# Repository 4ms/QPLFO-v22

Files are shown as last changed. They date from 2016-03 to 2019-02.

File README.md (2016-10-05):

#QPLFO v2.2
(also known as QPLFO v3)

This code runs on the STM32F030 version of the QPLFO, which is the factory-assembled version after March 2016. This code will not work on any kit versions of the QPLFO, nor any PCBs labeled version 1.x (green PCBs).

Note that one of the SWD programming pins is also used for the UI, so once the code has been flashed, it is difficult to re-flash it. The best technique I've found is to hit the reset button on the PCB at the right moment just before flashing.

This project was began using the [STM32F030x4 Application Template] (https://github.com/MrSpock/stm32f030x-gcc-template) from Martin Jurczuk, which is highly based on Mike Szczys [STM32F0-DISCOVERY template] (https://github.com/szczys/stm32f0-discovery-basic-template)

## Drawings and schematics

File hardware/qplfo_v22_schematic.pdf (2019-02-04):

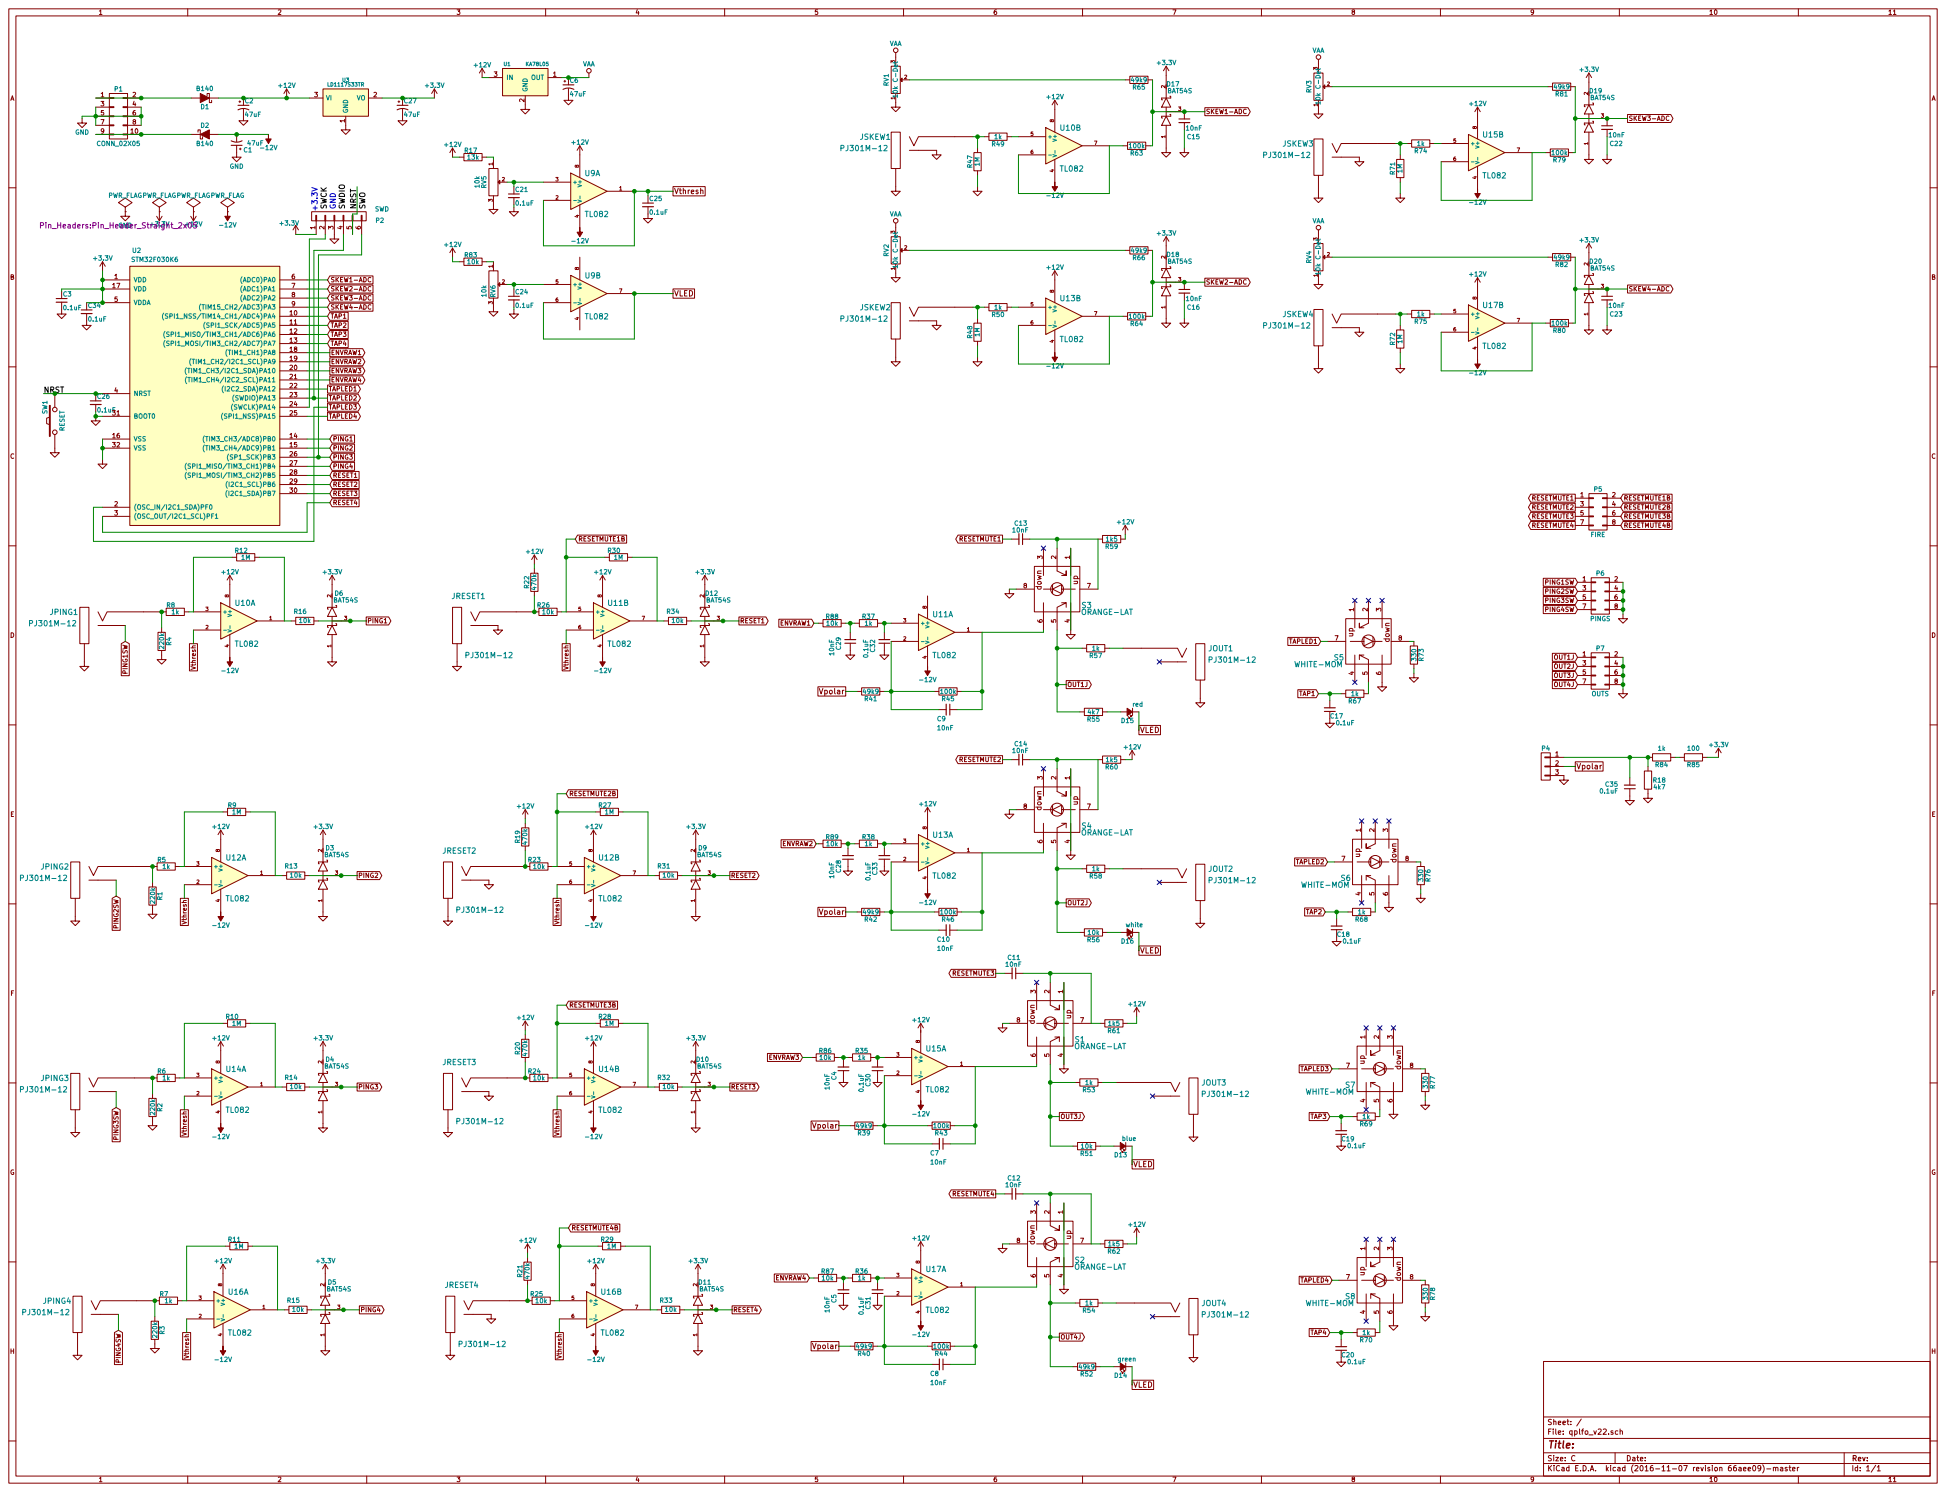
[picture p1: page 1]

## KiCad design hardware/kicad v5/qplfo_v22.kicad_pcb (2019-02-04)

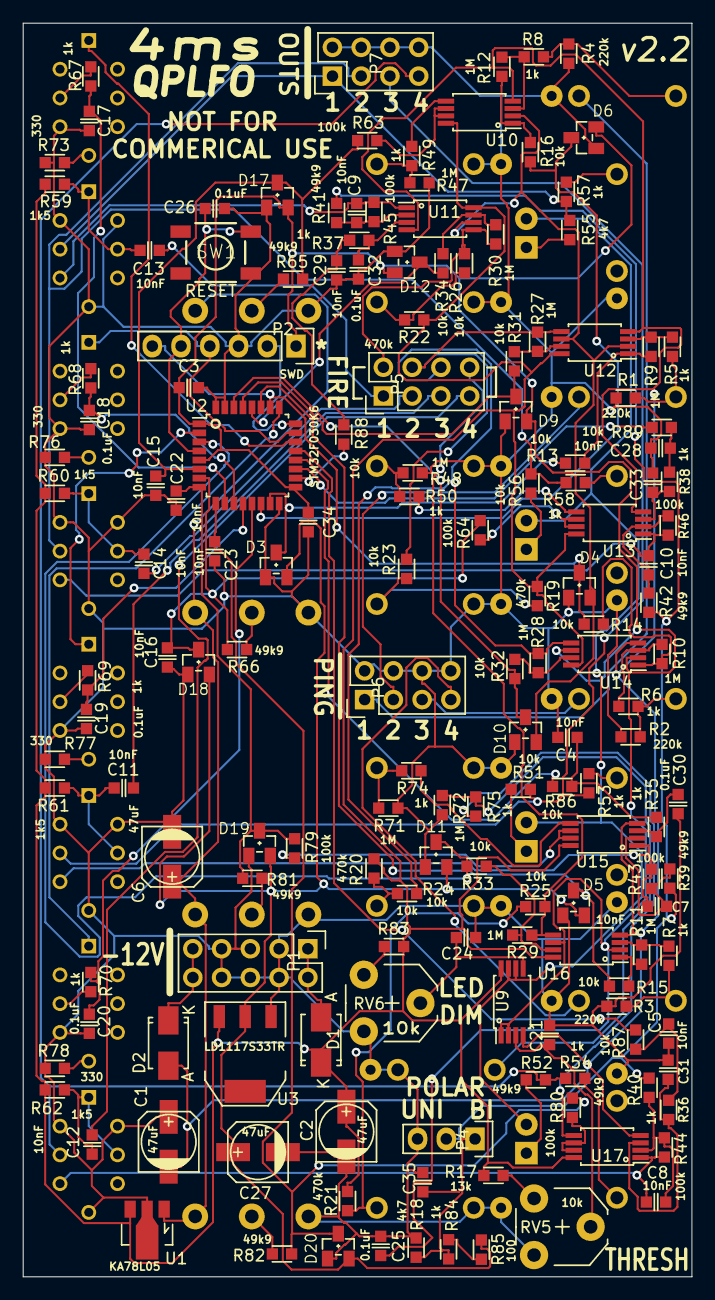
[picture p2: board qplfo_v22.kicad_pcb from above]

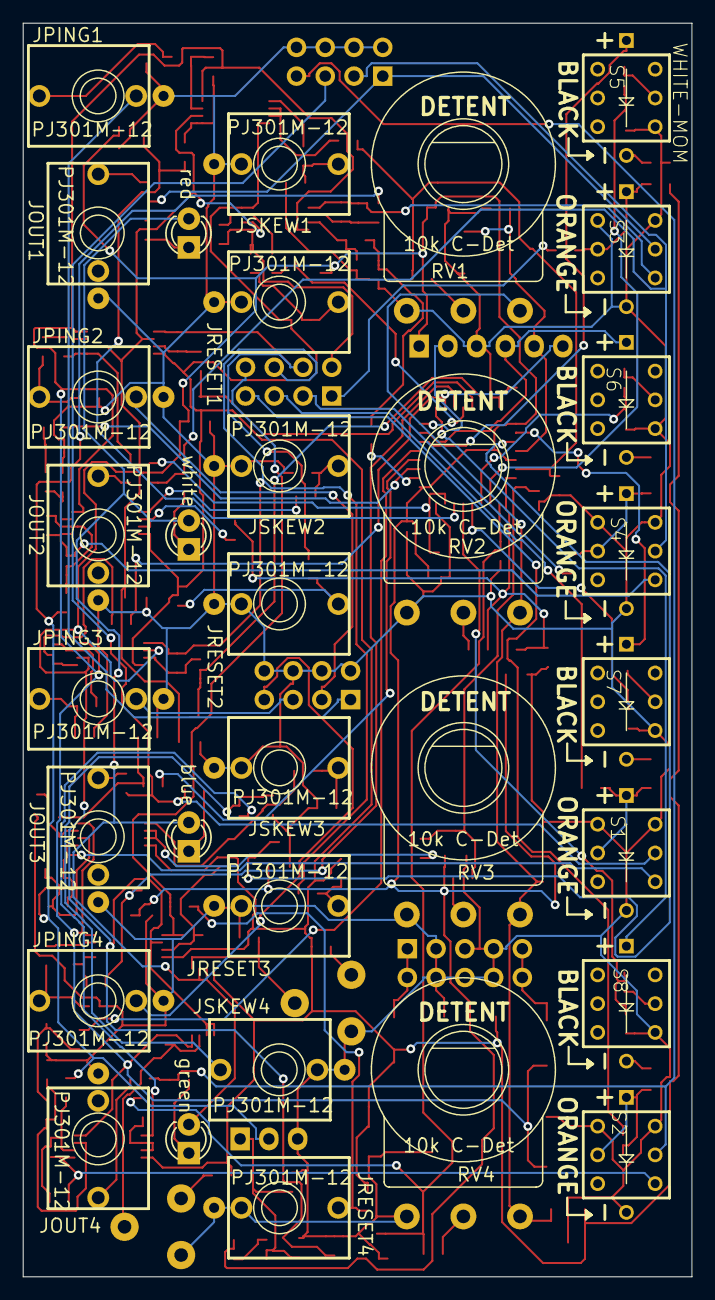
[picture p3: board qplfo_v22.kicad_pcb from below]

Board: 2 copper layers, 59.1 x 110.7 mm, 191 parts (32 on the bottom side), 130 nets.

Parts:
C1, C2, C6, C27: 47uF; c_elec_5x5.3
C3, C17, C18, C19, C20, C21, C24, C25, C26, C30, C31, C32, C33, C34, C35: 0.1uF; C0603
C4, C5, C7, C8, C9, C10, C11, C12, C13, C14, C15, C16, C22, C23, C28, C29: 10nF; C0603
D1, D2: B140; Diode-SMA_Standard
D3, D4, D5, D6, D9, D10, D11, D12, D17, D18, D19, D20: BAT54S; SOT23
D13: blue; LED-3MM-SQUARE-ANODE
D14: green; LED-3MM-SQUARE-ANODE
D15: red; LED-3MM-SQUARE-ANODE
D16: white; LED-3MM-SQUARE-ANODE
JOUT1, JOUT2, JOUT3, JOUT4: PJ301M-12; PJ301M-12-FIX
JPING1, JPING2, JPING3, JPING4: PJ301M-12; PJ301M-12-FIX
JRESET1, JRESET2, JRESET3, JRESET4: PJ301M-12; PJ301M-12-FIX
JSKEW1, JSKEW2, JSKEW3, JSKEW4: PJ301M-12; PJ301M-12-FIX
P1: CONN_02X05; Pin_Header_Straight_2x05
P2: SWD; Pin_Header_Straight_1x06
P4: HEADER-MALE-1X3-TH; Pin_Header_Straight_1x03
P5: FIRE; Pin_Header_Straight_2x04
P6: PINGS; Pin_Header_Straight_2x04
P7: OUTS; Pin_Header_Straight_2x04
R1, R2, R3, R4: 220k; R0603
R5, R6, R7, R8, R35, R36, R37, R38, R49, R50, R53, R54, R57, R58, R67, R68, R69, R70, R74, R75, R84: 1k; R0603
R9, R10, R11, R12, R27, R28, R29, R30, R47, R48, R71, R72: 1M; R0603
R13, R14, R15, R16, R23, R24, R25, R26, R31, R32, R33, R34, R51, R56, R83, R86, R87, R88, R89: 10k; R0603
R17: 13k; R0603
R18, R55: 4k7; R0603
R19, R20, R21, R22: 470k; R0603
R39, R40, R41, R42, R52, R65, R66, R81, R82: 49k9; R0603
R43, R44, R45, R46, R63, R64, R79, R80: 100k; R0603
R59, R60, R61, R62: 1k5; R0603
R73, R76, R77, R78: 330; R0603
R85: 100; R0603
RV1, RV2, RV3, RV4: 10k C-Det; 16MM-RV16AF-4A
RV5, RV6: 10k; Potentiometer_VishaySpectrol-Econtrim-Type36M
S1, S2, S3, S4: ORANGE-LAT; BUTTON-LED-PB61303
S5, S6, S7, S8: WHITE-MOM; BUTTON-LED-PB61303
SW1: RESET; BUTTON-TACT-SKQG
U1: KA78L05; SOT89-3_Housing
U2: STM32F030K6; LQFP-32_7x7mm_Pitch0.8mm
U3: LD1117S33TR; SOT-223
U9, U10, U11, U12, U13, U14, U15, U16, U17: TL082; TSSOP-8_4.4x3mm_Pitch0.65mm

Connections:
+3V3: C3.1, C27.1, C34.1, D3.2, D4.2, D5.2, D6.2, D9.2, D10.2, D11.2, D12.2, D17.2, D18.2, D19.2, D20.2, P2.1, R85.2, U2.1, U2.5, U2.17, U3.2
+12V: C2.1, D1.1, R17.2, R19.2, R20.2, R21.2, R22.2, R59.1, R60.1, R61.1, R62.1, R83.2, U1.3, U3.3, U9.8, U10.8, U11.8, U12.8, U13.8, U14.8, U15.8, U16.8, U17.8
-12V: C1.2, D2.2, U9.4, U10.4, U11.4, U12.4, U13.4, U14.4, U15.4, U16.4, U17.4
/NRST: C26.1, P2.5, SW1.2, U2.4
ENVRAW1: R88.2, U2.18
ENVRAW2: R89.2, U2.19
ENVRAW3: R86.2, U2.20
ENVRAW4: R87.2, U2.21
GND: C1.1, C2.2, C3.2, C4.1, C5.1, C6.2, C15.2, C16.2, C17.1, C18.1, C19.1, C20.1, C21.2, C22.2, C23.2, C24.2, C25.2, C26.2, C27.2, C28.1, C29.1, C30.1, C31.1, C32.1, C33.1, C34.2, C35.1, D3.1, D4.1, D5.1, D6.1, D9.1, D10.1, D11.1, D12.1, D17.1, D18.1, D19.1, D20.1, JOUT1.2, JOUT2.2, JOUT3.2, JOUT4.2, JPING1.2, JPING2.2, JPING3.2, JPING4.2, JRESET1.2, JRESET1.3, JRESET2.2, JRESET2.3, JRESET3.2, JRESET3.3, JRESET4.2, JRESET4.3, JSKEW1.2, JSKEW1.3, JSKEW2.2, JSKEW2.3, JSKEW3.2, JSKEW3.3, JSKEW4.2, JSKEW4.3, P1.3, P1.4, P1.5, P1.6, P1.7, P1.8, P2.3, P4.3, P6.2, P6.4, P6.6, P6.8, P7.2, P7.4, P7.6, P7.8, R1.2, R2.2, R3.2, R4.2, R18.2, R47.1, R48.1, R71.1, R72.1, R73.1, R76.1, R77.1, R78.1, RV1.1, RV2.1, RV3.1, RV4.1, RV5.3, RV6.3, S1.1, S1.4, S1.8, S2.1, S2.4, S2.8, S3.1, S3.4, S3.8, S4.1, S4.4, S4.8, S5.6, S6.6, S7.6, S8.6, SW1.1, U1.2, U2.16, U2.31, U2.32, U3.1
unnamed: C4.2, R35.2, R86.1
unnamed: C5.2, R36.2, R87.1
unnamed: C7.1, R43.1, S1.6, U15.1
unnamed: C7.2, R39.1, R43.2, U15.2
unnamed: C8.1, R44.1, S2.6, U17.1
unnamed: C8.2, R40.1, R44.2, U17.2
unnamed: C9.1, R45.1, S3.6, U11.1
unnamed: C9.2, R41.1, R45.2, U11.2
unnamed: C10.1, R46.1, S4.6, U13.1
unnamed: C10.2, R42.1, R46.2, U13.2
unnamed: C11.1, R61.2, S1.2, S1.7
unnamed: C12.1, R62.2, S2.2, S2.7
unnamed: C13.1, R59.2, S3.2, S3.7
unnamed: C14.1, R60.2, S4.2, S4.7
unnamed: C21.1, RV5.2, U9.3
unnamed: C24.1, RV6.2, U9.5
unnamed: C28.2, R38.2, R89.1
unnamed: C29.2, R37.2, R88.1
unnamed: C30.2, R35.1, U15.3
unnamed: C31.2, R36.1, U17.3
unnamed: C32.2, R37.1, U11.3
unnamed: C33.2, R38.1, U13.3
unnamed: C35.2, P4.1, R18.1, R84.1
unnamed: D1.2, P1.1, P1.2
unnamed: D2.1, P1.9, P1.10
unnamed: D13.2, R51.1
unnamed: D14.2, R52.1
unnamed: D15.2, R55.1
unnamed: D16.2, R56.1
unnamed: JOUT1.1, R57.1
unnamed: JOUT2.1, R58.1
unnamed: JOUT3.1, R53.1
unnamed: JOUT4.1, R54.1
unnamed: JPING1.1, R4.1, R8.2
unnamed: JPING2.1, R1.1, R5.2
unnamed: JPING3.1, R2.1, R6.2
unnamed: JPING4.1, R3.1, R7.2
unnamed: JRESET1.1, R22.1, R26.2
unnamed: JRESET2.1, R19.1, R23.2
unnamed: JRESET3.1, R20.1, R24.2
unnamed: JRESET4.1, R21.1, R25.2
unnamed: JSKEW1.1, R47.2, R49.2
unnamed: JSKEW2.1, R48.2, R50.2
unnamed: JSKEW3.1, R71.2, R74.2
unnamed: JSKEW4.1, R72.2, R75.2
unnamed: P2.2, U2.24
unnamed: R5.1, R9.2, U12.3
unnamed: R10.1, R14.1, U14.1
unnamed: R6.1, R10.2, U14.3
unnamed: R11.1, R15.1, U16.1
unnamed: R7.1, R11.2, U16.3
unnamed: R12.1, R16.1, U10.1
unnamed: R8.1, R12.2, U10.3
unnamed: R9.1, R13.1, U12.1
unnamed: R17.1, RV5.1
unnamed: R27.1, R31.1, U12.7
unnamed: R28.1, R32.1, U14.7
unnamed: R29.1, R33.1, U16.7
unnamed: R30.1, R34.1, U11.7
unnamed: R49.1, U10.5
unnamed: R50.1, U13.5
unnamed: R63.2, U10.6, U10.7
unnamed: R64.2, U13.6, U13.7
unnamed: R65.2, RV1.2
unnamed: R66.2, RV2.2
unnamed: R67.2, S5.5
unnamed: R68.2, S6.5
unnamed: R69.2, S7.5
unnamed: R70.2, S8.5
unnamed: R73.2, S5.8
unnamed: R74.1, U15.5
unnamed: R75.1, U17.5
unnamed: R76.2, S6.8
unnamed: R77.2, S7.8
unnamed: R78.2, S8.8
unnamed: R79.2, U15.6, U15.7
unnamed: R80.2, U17.6, U17.7
unnamed: R81.2, RV3.2
unnamed: R82.2, RV4.2
unnamed: R83.1, RV6.1
unnamed: R84.2, R85.1
OUT1J: P7.1, R55.2, R57.2, S3.5
OUT2J: P7.3, R56.2, R58.2, S4.5
OUT3J: P7.5, R51.2, R53.2, S1.5
OUT4J: P7.7, R52.2, R54.2, S2.5
PING1: D6.3, R16.2, U2.14
PING1SW: JPING1.3, P6.1
PING2: D3.3, R13.2, U2.15
PING2SW: JPING2.3, P6.3
PING3: D4.3, P2.6, R14.2, U2.26
PING3SW: JPING3.3, P6.5
PING4: D5.3, R15.2, U2.27
PING4SW: JPING4.3, P6.7
RESET1: D12.3, R34.2, U2.28
RESET2: D9.3, R31.2, U2.29
RESET3: D10.3, R32.2, U2.30
RESET4: D11.3, R33.2, U2.3
RESETMUTE1: C13.2, P5.1
RESETMUTE1B: P5.2, R26.1, R30.2, U11.5
RESETMUTE2: C14.2, P5.3
RESETMUTE2B: P5.4, R23.1, R27.2, U12.5
RESETMUTE3: C11.2, P5.5
RESETMUTE3B: P5.6, R24.1, R28.2, U14.5
RESETMUTE4: C12.2, P5.7
RESETMUTE4B: P5.8, R25.1, R29.2, U16.5
SKEW1-ADC: C15.1, D17.3, R63.1, R65.1, U2.6
SKEW2-ADC: C16.1, D18.3, R64.1, R66.1, U2.7
SKEW3-ADC: C22.1, D19.3, R79.1, R81.1, U2.8
SKEW4-ADC: C23.1, D20.3, R80.1, R82.1, U2.9
TAP1: C17.2, R67.1, U2.10
TAP2: C18.2, R68.1, U2.11
TAP3: C19.2, R69.1, U2.12
TAP4: C20.2, R70.1, U2.13
TAPLED1: S5.7, U2.22
TAPLED2: P2.4, S6.7, U2.23
TAPLED3: S7.7, U2.2
TAPLED4: S8.7, U2.25
VAA: C6.1, RV1.3, RV2.3, RV3.3, RV4.3, U1.1
VLED: D13.1, D14.1, D15.1, D16.1, U9.6, U9.7
Vpolar: P4.2, R39.2, R40.2, R41.2, R42.2
Vthresh: C25.1, U9.1, U9.2, U10.2, U11.6, U12.2, U12.6, U14.2, U14.6, U16.2, U16.6

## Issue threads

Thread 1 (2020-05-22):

qplfo_v22-rescue.lib missing

okelk, 2020-05-22:
Schematic file is unusable because it references "qplfo_v22-rescue.lib" that is not included in the folder.
I'm using kicad 5.1.5.

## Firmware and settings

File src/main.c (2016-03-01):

#include "stm32f0xx_conf.h"
#include "dig_inouts.h"
#include "pwm.h"
#include "adc.h"


//#define FREERUN


/************************
 * Time keeping			*
 ************************/
volatile uint32_t tmr_ping[4]={0,0,0,0};
volatile uint32_t tmr_reset[4]={0,0,0,0};
volatile uint32_t tmr_tapin[4]={0,0,0,0};
volatile uint32_t tmr_tapout[4]={0,0,0,0};
volatile uint32_t ping_irq_timestamp[4]={0,0,0,0};

/************************
 * Mnuemonics			*
 ************************/
#define WAIT 0
#define RISE 1
#define FALL 2


/********************
 * Settings			*
 ********************/
#define ADC_DRIFT 50

#define PLUCKY_CURVE_ADC 130
#define PLUCKY_CUBIC_ADC 90
#define PLUCKY_QUADRATIC_ADC 55
#define TRIGOUT_CURVE_ADC 30

#define TRIGOUT_WIDTH 50

#define SKEW_TRACKING_TIME 4000

#define HOLDTIMECLEAR 15000

/********************
 * Global variables	*
 ********************/
volatile uint8_t timer_overflowed=0;
uint8_t ping_state[4]={0,0,0,0};
volatile uint8_t clk_time_changed[4]={0,0,0,0};
volatile uint16_t adc_buffer[4];
int16_t t_dacout[4]={0,0,0,0};


void SysTick_Handler(void) {

 	tmr_ping[0]++;
	tmr_ping[1]++;
	tmr_ping[2]++;
	tmr_ping[3]++;
	tmr_reset[0]++;
	tmr_reset[1]++;
	tmr_reset[2]++;
	tmr_reset[3]++;
	tmr_tapin[0]++;
	tmr_tapin[1]++;
	tmr_tapin[2]++;
	tmr_tapin[3]++;
	tmr_tapout[0]++;
	tmr_tapout[1]++;
	tmr_tapout[2]++;
	tmr_tapout[3]++;

	timer_overflowed++;
}


void init_tmrs(void)
{
	tmr_ping[0]=0;
	tmr_ping[1]=0;
	tmr_ping[2]=0;
	tmr_ping[3]=0;
	tmr_reset[0]=0;
	tmr_reset[1]=0;
	tmr_reset[2]=0;
	tmr_reset[3]=0;
	tmr_tapin[0]=0;
	tmr_tapin[1]=0;
	tmr_tapin[2]=0;
	tmr_tapin[3]=0;
	tmr_tapout[0]=0;
	tmr_tapout[1]=0;
	tmr_tapout[2]=0;
	tmr_tapout[3]=0;
}

inline uint8_t diff(uint8_t a, uint8_t b);
inline uint8_t diff(uint8_t a, uint8_t b){
	if (a>b) return (a-b);
	else return (b-a);
}
/*
#define delay()					\
do {							\
  register unsigned int i;		\
  for (i = 0; i < 1000000; ++i)	\
    __asm__ __volatile__ ("nop\n\t":::"memory");\
} while (0)
*/

uint32_t calc_rise_time(uint32_t skew_val, uint32_t period);
uint32_t calc_rise_time(uint32_t skew_val, uint32_t period)
{
	if (skew_val<=(PLUCKY_CURVE_ADC+ADC_DRIFT+ADC_DRIFT))
	{
		return(1);
	}
	else if (skew_val>4000)
	{
		return(period-1);
	}
	else if ((skew_val>1975) && (skew_val<2125))
	{
		return(period>>1);
	}
	else
	{
		return((skew_val * period) >> 12);
	}
}

int main(void)
{
	uint32_t clk_time[4]={0,0,0,0};

	uint8_t env_state[4]={RISE, RISE, RISE, RISE};
	uint8_t reset_now_flag[4]={0,0,0,0};

	uint32_t rise_time[4]={0,0,0,0};
	uint32_t fall_time[4]={0,0,0,0};

	uint32_t rise_inc[4]={0,0,0,0};
	uint32_t fall_inc[4]={0,0,0,0};
	uint32_t accum[4]={0,0,0,0};

	uint32_t reset_offset_time[4]={0,0,0,0};
	uint8_t ready_to_reset[4]={0,0,0,0};
	uint8_t reset_up[4]={0,0,0,0};

	uint32_t skew_adc[4]={2047,2047,2047,2047};

	uint8_t do_plucky_curve[4]={0,0,0,0};
	uint32_t sample_ctr[4]={0,0,0,0};
	uint32_t is_modulating_skew[4]={0,0,0,0};

	uint8_t t=0;
	uint8_t i;
	uint32_t t32=0;
	uint16_t t16;
	uint32_t new_clk_time;

	uint8_t t_of;

	uint32_t now;

	uint8_t chan=0;

	uint8_t running[4];
	uint8_t tapin_up[4]={0,0,0,0};
	uint8_t tapled_state[4];
	uint8_t ping_high[4]={0,0,0,0};


	/** Initialize **/

	init_tmrs();
	init_dig_inouts();
	init_adc((uint16_t *)adc_buffer);

	//delay();

	init_pwm();
	SysTick_Config(SystemCoreClock/10000); //1000 is 1ms ticks, 10000 is 100us ticks, 100000 is 10us ticks

	TAPLED_OFF(1);
	TAPLED_OFF(2);
	TAPLED_OFF(3);
	TAPLED_OFF(0);
	tapled_state[0]=0;
	tapled_state[1]=0;
	tapled_state[2]=0;
	tapled_state[3]=0;

	running[0]=0;
	running[1]=0;
	running[2]=0;
	running[3]=0;

	clk_time[0]=0;
	clk_time[1]=0;
	clk_time[2]=0;
	clk_time[3]=0;

	while (1){

		if (++chan>=4) chan=0;

		/***************** READ PING *********************
		 *  On rising edge of input ping, record the time
		 *  since the last ping. Save this into clk_time
		 *************************************************/

		if (TAPBUT(chan))
		{
			if (!(tapin_up[chan]))
			{
				if (running[chan]==1) running[chan]=2;
				else if (running[chan]==0) running[chan]=1;

				tapled_state[chan]=1;
				TAPLED_ON(chan);
				tapin_up[chan]=1;

				clk_time[chan] = tmr_tapin[chan];

				tmr_tapin[chan]=0;
				tmr_tapout[chan]=0;
				tmr_reset[chan]=0;
				ready_to_reset[chan]=1;

				clk_time_changed[chan]=1;
			}
			//Check for long hold of tap button
			if (tmr_tapin[chan] > HOLDTIMECLEAR)
			{
				if (running[chan])
				{
					TAPLED_OFF(chan);
					tapled_state[chan]=0;
				}
				running[chan]=0;
				//clk_time[chan]=0;
			}
		} else {
			if (tapin_up[chan])
			{
				tapin_up[chan]=0;
				tapled_state[chan]=0;
				TAPLED_OFF(chan);
			}
		}


		if (PING(chan))
		{
			if (!(ping_high[chan])){
				running[chan]=2;

				tapled_state[chan]=1;
				TAPLED_ON(chan);
				ping_high[chan]=1;

				new_clk_time = tmr_ping[chan];

				if (new_clk_time > clk_time[chan])	t32=new_clk_time - clk_time[chan];
				else t32=clk_time[chan]-new_clk_time;

				if (t32>10){ //better would be to make it a percent of clk_time
					clk_time[chan] = new_clk_time;
					clk_time_changed[chan]=1;
				}

				tmr_ping[chan]=0;
				tmr_tapout[chan]=0;
				tmr_reset[chan]=0;
				ready_to_reset[chan]=1;

			}
		} else {
			if (ping_high[chan]){
				ping_high[chan]=0;
				tapled_state[chan]=0;
				TAPLED_OFF(chan);
			}
		}


		//
		// Flash the TAP button LED with a 50% duty cycle
		// Reset Tap LED timer if it overflows the channel's period
		//
		if (running[chan]==2){
			now = tmr_tapout[chan];
			if (tapled_state[chan] && (now >= (clk_time[chan] >> 1)))
			{
				tapled_state[chan]=0;
				TAPLED_OFF(chan);
			}

			if (now >= clk_time[chan]){
				t32 = (now - clk_time[chan]);
				tmr_tapout[chan]=t32;
				tmr_reset[chan]=t32;

				//tmr_tapout[chan]=0;

				tapled_state[chan]=1;
				ready_to_reset[chan]=1;
				TAPLED_ON(chan);
			}
		}


		if (clk_time_changed[chan])
		{
			clk_time_changed[chan]=0;

			tmr_reset[chan]=0;

			//clk_time changed, so see if reset_offset_time is still valid
			//reset it to 0 if it's greater than the ping period or 2ms under the period
			if ((reset_offset_time[chan]+20)>=clk_time[chan]) {
				reset_offset_time[chan]=0;
			}

			ready_to_reset[chan]=1;

			rise_time[chan] = calc_rise_time(skew_adc[chan], clk_time[chan]);
			fall_time[chan] = clk_time[chan] - rise_time[chan];

			rise_inc[chan] = (1<<28)/(rise_time[chan]);
			fall_inc[chan] = (1<<28)/(fall_time[chan]);

		}



		if (RESETJACK(chan))
		{
			if (!reset_up[chan])
			{
			//	if (env_state!=WAIT){
					reset_offset_time[chan]=tmr_reset[chan];

					//see if the new reset_offset_time is still valid
					//reset it to 0 if it's greater than the ping period or 2ms under the period
					if ((reset_offset_time[chan]+20)>=clk_time[chan]) {
						reset_offset_time[chan]=0;
					}
			//	}

				reset_now_flag[chan]=1;
				reset_up[chan]=1;
				ready_to_reset[chan]=0;
			}
			else
			{
				if (env_state[chan]!=WAIT)
					ready_to_reset[chan]=0; //disable resetting if RESET is held high "analog mode"
			}
		}
		else
		{
			reset_up[chan]=0;
		}



		/*******************
		*
		* Reset Lock Point
		*
		********************/

		t32=tmr_reset[chan];

		if (ready_to_reset[chan] && (t32>reset_offset_time[chan]))
		{
			//If we haven't recently modulated skew, then force a reset
			if (is_modulating_skew[chan]==0)
				reset_now_flag[chan]=1;

			if (env_state[chan]==WAIT)
				reset_now_flag[chan]=1;
			ready_to_reset[chan]=0;
		}



		/********************* READ SKEW ADC ************************
		 * 		Read the ADC for the Skew value.       			*
		 *		If it's changed more than ADC_DRIFT,    		*
		 *		re-cacluate the rise and fall times     		*
		 ********************************************************/

		t16=adc_buffer[chan];
		if (skew_adc[chan]>t16)
			t=skew_adc[chan]-t16;
		else
			t=t16-skew_adc[chan];

		if (t>ADC_DRIFT)
		{
			is_modulating_skew[chan]=SKEW_TRACKING_TIME;
			skew_adc[chan]=adc_buffer[chan];

			rise_time[chan] = calc_rise_time(skew_adc[chan], clk_time[chan]);
			fall_time[chan]=clk_time[chan]-rise_time[chan];

			rise_inc[chan]=(1<<28)/(rise_time[chan]);
			fall_inc[chan]=(1<<28)/(fall_time[chan]);

		}
		else
		{
			if (is_modulating_skew[chan]>0)
				is_modulating_skew[chan]--;
		}


		/**************** UPDATE THE ENVELOPE *******************
		 *  Update only when timer has overflowed
		 * -restart if needed
		 * -calculate new position
		 * -change curve step (RISE/FALL)
		 ********************************************************/

		if (chan==3)
		{

			t_of=timer_overflowed;

			if (t_of /*|| reset_now_flag[i]*/)
			{

				for (i=0;i<4;i++)
				{

					// Handle the reset_now_flag by resetting the envelope
					if (reset_now_flag[i])
					{
						reset_now_flag[i]=0;

						env_state[i]=RISE;

						if (skew_adc[i]<=PLUCKY_CURVE_ADC)
						{
							if (skew_adc[i]<=TRIGOUT_CURVE_ADC)
								do_plucky_curve[i]=1;
							else
								do_plucky_curve[i]=skew_adc[i];
						}
						else
						{
							do_plucky_curve[i]=0;
						}

						accum[i]=0;
						sample_ctr[i]=0;
					}

					t_dacout[i]=0;
					sample_ctr[i]++;
					switch (env_state[i])
					{
						case(RISE):
							accum[i] += rise_inc[i] * t_of;
							t_dacout[i]=accum[i]>>18;

							if (t_dacout[i]>=1023)
							{
								accum[i]=1023<<18;
								t_dacout[i]=1023;
								env_state[i]=FALL;
							}
						break;


						case(FALL):

							if (accum[i] > (fall_inc[i] * t_of))
							accum[i] -= fall_inc[i] * t_of;
							else accum[i]=0;

							t_dacout[i] = accum[i]>>18;

							if ((t_dacout[i]<1) || (t_dacout[i]>1023)){
								accum[i]=0;
								t_dacout[i]=0;

								#ifndef FREERUN
									env_state[i]=WAIT;

									//when modulating skew with a slower LFO:
									//usually we don't get to env_state=RISE because of the clk_time comparison, but sometimes it's because is_mod_skew==0
									if (RESETJACK(i) || (is_modulating_skew[i]>0)){

										t32=tmr_reset[i]>>1; //half the time since the last ping

										if (t32<clk_time[i])//if time since last ping is less than twice the LFO period
										{
											env_state[i]=RISE;

											if (skew_adc[i]<=PLUCKY_CURVE_ADC)
											{
												if (skew_adc[i]<=TRIGOUT_CURVE_ADC)
													do_plucky_curve[i]=1;
												else
													do_plucky_curve[i] = skew_adc[i];
											}
											else
											{
												do_plucky_curve[i]=0;
											}
											sample_ctr[i]=0;

										}
									}
								#else
									reset_now_flag[i]=1;
								#endif
								//clk_time_changed[i]=0;
							}
						break;

						default:
							env_state[i]=WAIT;

							accum[i]=0;
							t_dacout[i]=0;
						break;

					}

					if (do_plucky_curve[i])
					{
						//TRIGOUT
						if (do_plucky_curve[i]==1)
						{
							if (sample_ctr[i]<TRIGOUT_WIDTH)
								t_dacout[i]=1023;
							else
								t_dacout[i]=1;
						}
						else //CURVEOUT
						{
							//square
							t_dacout[i]=(((int32_t)t_dacout[i])*((int32_t)t_dacout[i]))>>10;

							//cubic
							if (do_plucky_curve[i]<=PLUCKY_CUBIC_ADC)
								t_dacout[i]=(((int32_t)t_dacout[i])*((int32_t)t_dacout[i]))>>10;

							if (do_plucky_curve[i]<=PLUCKY_QUADRATIC_ADC)
								t_dacout[i]=(((int32_t)t_dacout[i])*((int32_t)t_dacout[i]))>>10;
						}

					}

				} //loop i

				timer_overflowed-=t_of;

				TIM_SetCompare1(TIM1, t_dacout[0]);
				TIM_SetCompare2(TIM1, t_dacout[1]);
				TIM_SetCompare3(TIM1, t_dacout[2]);
				TIM_SetCompare4(TIM1, t_dacout[3]);

			} //if (t_of)
		} //chan==3
	}
}

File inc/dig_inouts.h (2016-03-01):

/*
 * dig_inouts.h
 */

#ifndef INOUTS_H_
#define INOUTS_H_

#include <stm32f0xx.h>

//INPUTS
//ADC: GPIOA GPIO_Pin_0 GPIO_Pin_1 GPIO_Pin_2 GPIO_Pin_3

//DEBUG_VERSION will disable the Tap Button LED for channel 2 (it's used by the SWD connection)
//#define DEBUG_VERSION
#define RELEASE_VERSION

#define TAPBUT_RCC RCC_AHBPeriph_GPIOA

#define TAPBUT_GPIO GPIOA
#define TAPBUT1_pin GPIO_Pin_4
#define TAPBUT1 (!(TAPBUT_GPIO->IDR & TAPBUT1_pin))
#define TAPBUT2_pin GPIO_Pin_5
#define TAPBUT2 (!(TAPBUT_GPIO->IDR & TAPBUT2_pin))
#define TAPBUT3_pin GPIO_Pin_6
#define TAPBUT3 (!(TAPBUT_GPIO->IDR & TAPBUT3_pin))
#define TAPBUT4_pin GPIO_Pin_7
#define TAPBUT4 (!(TAPBUT_GPIO->IDR & TAPBUT4_pin))

#define PING_RCC RCC_AHBPeriph_GPIOB
#define PING_GPIO GPIOB
#define PING1_pin GPIO_Pin_0
#define PING1 ((PING_GPIO->IDR & PING1_pin))
#define PING2_pin GPIO_Pin_1
#define PING2 ((PING_GPIO->IDR & PING2_pin))
#define PING3_pin GPIO_Pin_3
#define PING3 ((PING_GPIO->IDR & PING3_pin))
#define PING4_pin GPIO_Pin_4
#define PING4 ((PING_GPIO->IDR & PING4_pin))


#define RESET_RCC (RCC_AHBPeriph_GPIOB | RCC_AHBPeriph_GPIOF)

#define RESET123_GPIO GPIOB
#define RESET1_pin GPIO_Pin_5
#define RESET1 ((RESET123_GPIO->IDR & RESET1_pin))
#define RESET2_pin GPIO_Pin_6
#define RESET2 ((RESET123_GPIO->IDR & RESET2_pin))
#define RESET3_pin GPIO_Pin_7
#define RESET3 ((RESET123_GPIO->IDR & RESET3_pin))

#define RESET4_GPIO GPIOF
#define RESET4_pin GPIO_Pin_1
#define RESET4 ((RESET4_GPIO->IDR & RESET4_pin))


/*
#define EXTI_CLOCK_GPIO EXTI_PortSourceGPIOB
#define EXTI_CLOCK_pin EXTI_PinSource12
#define EXTI_CLOCK_line EXTI_Line12
#define EXTI_CLOCK_IRQ EXTI15_10_IRQn
*/


//OUTPUTS

#define TAPLED_RCC (RCC_AHBPeriph_GPIOA | RCC_AHBPeriph_GPIOF)
#define TAPLED1_GPIO GPIOA
#define TAPLED2_GPIO GPIOA
#define TAPLED3_GPIO GPIOF
#define TAPLED4_GPIO GPIOA

#define TAPLED1_pin GPIO_Pin_12
#define TAPLED2_pin GPIO_Pin_13
#define TAPLED3_pin GPIO_Pin_0
#define TAPLED4_pin GPIO_Pin_15

#define TAPLED1_ON TAPLED1_GPIO->BSRRL = TAPLED1_pin
#define TAPLED1_OFF TAPLED1_GPIO->BSRRH = TAPLED1_pin

#define TAPLED2_ON TAPLED2_GPIO->BSRRL = TAPLED2_pin
#define TAPLED2_OFF TAPLED2_GPIO->BSRRH = TAPLED2_pin

#define TAPLED3_ON TAPLED3_GPIO->BSRRL = TAPLED3_pin
#define TAPLED3_OFF TAPLED3_GPIO->BSRRH = TAPLED3_pin

#define TAPLED4_ON TAPLED4_GPIO->BSRRL = TAPLED4_pin
#define TAPLED4_OFF TAPLED4_GPIO->BSRRH = TAPLED4_pin


#define LFOPWM_GPIO_RCC RCC_AHBPeriph_GPIOA
#define LFOPWM_GPIO GPIOA
#define LFOPWM1_pin GPIO_Pin_8
#define LFOPWM2_pin GPIO_Pin_9
#define LFOPWM3_pin GPIO_Pin_10
#define LFOPWM4_pin GPIO_Pin_11

#define LFOPWM1_source GPIO_PinSource8
#define LFOPWM2_source GPIO_PinSource9
#define LFOPWM3_source GPIO_PinSource10
#define LFOPWM4_source GPIO_PinSource11

void init_dig_inouts(void);
void init_EXTI_inputs(void);
void init_inputread_timer(void);

void TAPLED_ON(uint8_t x);
void TAPLED_OFF(uint8_t x);
uint32_t TAPBUT(uint8_t x);
uint32_t PING(uint8_t x);
uint32_t RESETJACK(uint8_t x);

#endif /* INOUTS_H_ */

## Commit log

2014-09-06 repo init with working code and example
    [stm32f0-openocd.cfg]
2016-03-01 Initial release for PCB 3.0
2016-10-05 First public commit, Updated license and README
    [stm32f0-openocd.cfg]
2019-02-04 Added hardware files: kicad v4 and v5 projects, gerbers, and schematic PDF (in case you don't have kicad)
    [qplfo_v22-B_Cu.gbr, qplfo_v22-B_Mask.gbr, qplfo_v22-B_SilkS.gbr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]
